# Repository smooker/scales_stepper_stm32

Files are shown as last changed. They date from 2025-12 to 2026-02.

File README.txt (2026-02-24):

Black Pill F4 pinout blackmagic probe
https://github.com/blackmagic-debug/blackmagic/tree/main/src/platforms/common/blackpill-f4

PB8 - SWDCLK - white
PB9 - SWDDIO - gray
GND - purple

Pylnata opitna postanovka - logic analizer + blackmagic probe + stm32f103 blue pill

[Mon Dec  8 10:38:55 2025] usb 3-3: new high-speed USB device number 18 using xhci_hcd
[Mon Dec  8 10:38:56 2025] usb 3-3: New USB device found, idVendor=0403, idProduct=6010, bcdDevice= 7.00
[Mon Dec  8 10:38:56 2025] usb 3-3: New USB device strings: Mfr=1, Product=2, SerialNumber=3
[Mon Dec  8 10:38:56 2025] usb 3-3: Product: USB <-> Serial Converter
[Mon Dec  8 10:38:56 2025] usb 3-3: Manufacturer: FTDI
[Mon Dec  8 10:38:56 2025] usb 3-3: SerialNumber: FT2232HL
[Mon Dec  8 10:38:56 2025] ftdi_sio 3-3:1.0: FTDI USB Serial Device converter detected
[Mon Dec  8 10:38:56 2025] usb 3-3: Detected FT2232H
[Mon Dec  8 10:38:56 2025] usb 3-3: FTDI USB Serial Device converter now attached to ttyUSB0
[Mon Dec  8 10:38:56 2025] ftdi_sio 3-3:1.1: FTDI USB Serial Device converter detected
[Mon Dec  8 10:38:56 2025] usb 3-3: Detected FT2232H
[Mon Dec  8 10:38:56 2025] usb 3-3: FTDI USB Serial Device converter now attached to ttyUSB1
[Mon Dec  8 10:40:39 2025] usb 3-5: new full-speed USB device number 19 using xhci_hcd
[Mon Dec  8 10:40:39 2025] usb 3-5: New USB device found, idVendor=0483, idProduct=5740, bcdDevice= 2.00
[Mon Dec  8 10:40:39 2025] usb 3-5: New USB device strings: Mfr=1, Product=2, SerialNumber=3
[Mon Dec  8 10:40:39 2025] usb 3-5: Product: STM32 Virtual ComPort
[Mon Dec  8 10:40:39 2025] usb 3-5: Manufacturer: STMicroelectronics
[Mon Dec  8 10:40:39 2025] usb 3-5: SerialNumber: 6D8131955348
[Mon Dec  8 10:40:39 2025] cdc_acm 3-5:1.0: ttyACM0: USB ACM device
[Mon Dec  8 10:40:48 2025] usb 3-2: new full-speed USB device number 20 using xhci_hcd
[Mon Dec  8 10:40:48 2025] usb 3-2: New USB device found, idVendor=1d50, idProduct=6018, bcdDevice= 2.00
[Mon Dec  8 10:40:48 2025] usb 3-2: New USB device strings: Mfr=1, Product=2, SerialNumber=3
[Mon Dec  8 10:40:48 2025] usb 3-2: Product: Black Magic Probe (BlackPill-F411CE) v2.0.0-rc1-38-gf4e79b65
[Mon Dec  8 10:40:48 2025] usb 3-2: Manufacturer: Black Magic Debug
[Mon Dec  8 10:40:48 2025] usb 3-2: SerialNumber: 3368334B3134
[Mon Dec  8 10:40:48 2025] cdc_acm 3-2:1.0: ttyACM1: USB ACM device
[Mon Dec  8 10:40:48 2025] cdc_acm 3-2:1.2: ttyACM2: USB ACM device

104849 smooker@sw1 ~/src/stm32/scales_stepper_malinovski $ cat ./USB_DEVICE/App/usbd_desc.c | grep -e USBD_PID -e USBD_VID
#define USBD_VID     1155
#define USBD_PID_FS     22336

104935 smooker@sw1 ~/src/stm32/scales_stepper_malinovski $ hex2dec.pl 1155
HEX:0483
DEC:1155
BIN:     10010000011
104941 smooker@sw1 ~/src/stm32/scales_stepper_malinovski $ hex2dec.pl 22336
HEX:5740
DEC:22336
BIN: 101011101000000
104947 smooker@sw1 ~/src/stm32/scales_stepper_malinovski $

https://github.com/STMicroelectronics/STM32CubeF3/blob/master/Projects/STM32373C_EVAL/Applications/EEPROM/EEPROM_Emulation/Src/eeprom.c

optimize
smooker@sw2 ~/src/stm32/scales_stepper_stm32 $ arm-none-eabi-size ./build/scales_stepper_stm32.elf
   text	   data	    bss	    dec	    hex	filename
  49128	    964	   5568	  55660	   d96c	./build/scales_stepper_stm32.elf

   text	   data	    bss	    dec	    hex	filename
  56336	    964	   5568	  62868	   f594	./build/scales_stepper_stm32.elf

with link.sh
   text	   data	    bss	    dec	    hex	filename
  49128	    964	   5568	  55660	   d96c	./build/scales_stepper_stm32.elf

with newlib 4.6.0
arm-none-eabi-size build/scales_stepper_stm32.elf
   text    data     bss     dec     hex filename
  56312    1196    5568   63076    f664 build/scales_stepper_stm32.elf
arm-none-eabi-objcopy -O ihex build/scales_stepper_stm32.elf build/scales_stepper_stm32.hex

after link.sh
smooker@sw2 ~/src/stm32/scales_stepper_stm32 $ ./link.sh 
   text	   data	    bss	    dec	    hex	filename
  49104	   1196	   5568	  55868	   da3c	./build/scales_stepper_stm32.elf

without enable of printf and scanf
arm-none-eabi-size build/scales_stepper_stm32.elf
   text	   data	    bss	    dec	    hex	filename
  37276	    588	   5560	  43424	   a9a0	build/scales_stepper_stm32.elf
arm-none-eabi-objcopy -O ihex build/scales_stepper_stm32.elf build/scales_stepper_stm32.hex

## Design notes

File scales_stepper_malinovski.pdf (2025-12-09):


21/11/2025

scales_stepper_malinovski Project Configuration Report

## 1. Description

### 1.1. Project

Project Name | scales_stepper_malinovski
Board Name | custom
Generated with: | STM32CubeMX 6.13.0
Date | 11/21/2025

### 1.2. MCU

MCU Series | STM32F1
MCU Line | STM32F103
MCU name | STM32F103C6Tx
MCU Package | LQFP48
MCU Pin number | 48

### 1.3. Core(s) information

Core(s) | Arm Cortex-M3

## 2. Pinout Configuration

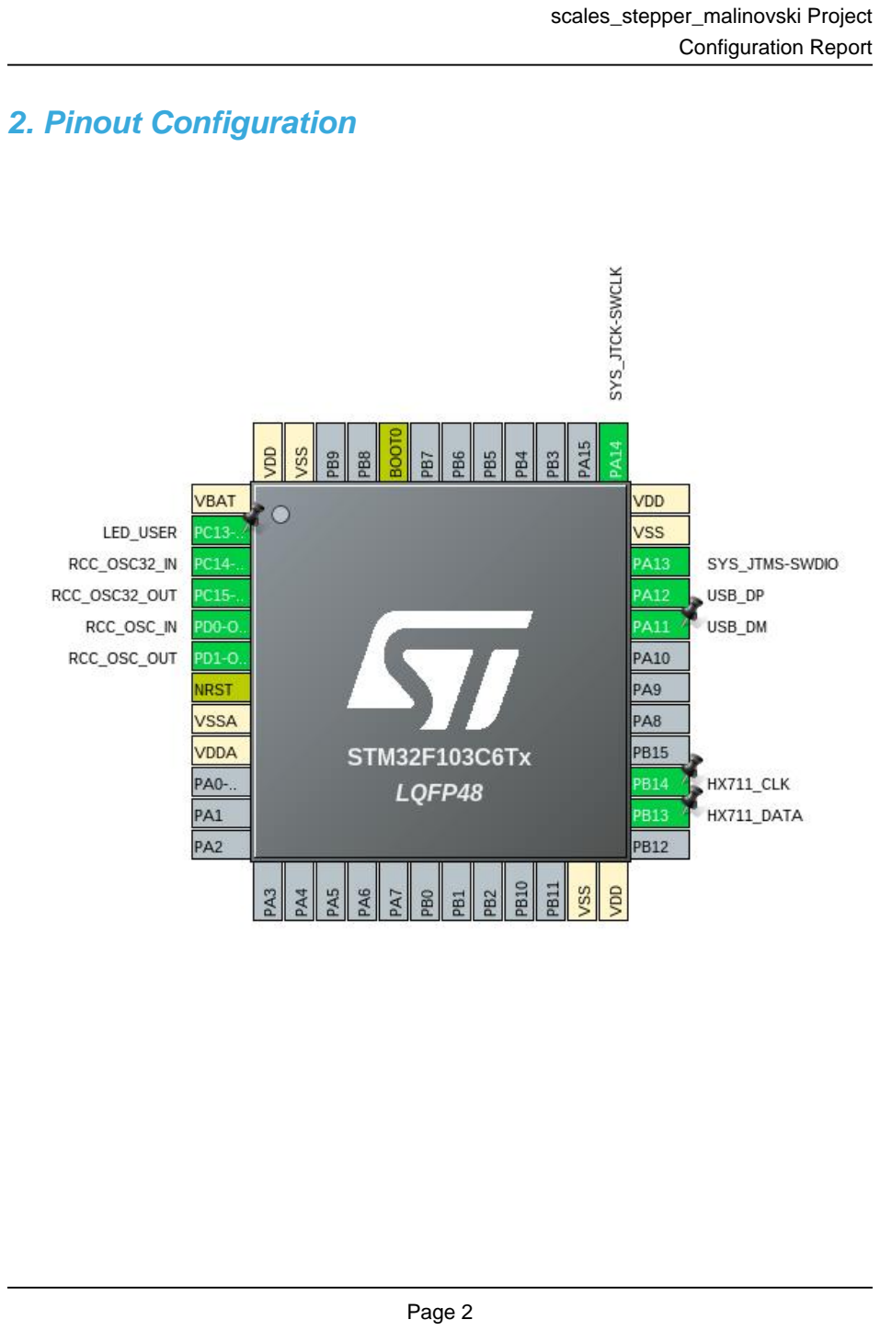
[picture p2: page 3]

## 3. Pins Configuration

Pin Number LQFP48 | Pin Name (function after reset) | Pin Type | Alternate Function(s) | Label
1 | VBAT | Power
2 | PC13-TAMPER-RTC * | I/O | GPIO_Output | LED_USER
3 | PC14-OSC32_IN | I/O | RCC_OSC32_IN
4 | PC15-OSC32_OUT | I/O | RCC_OSC32_OUT
5 | PD0-OSC_IN | I/O | RCC_OSC_IN
6 | PD1-OSC_OUT | I/O | RCC_OSC_OUT
7 | NRST | Reset
8 | VSSA | Power
9 | VDDA | Power
23 | VSS | Power
24 | VDD | Power
26 | PB13 * | I/O | GPIO_Input | HX711_DATA
27 | PB14 * | I/O | GPIO_Output | HX711_CLK
32 | PA11 | I/O | USB_DM
33 | PA12 | I/O | USB_DP
34 | PA13 | I/O | SYS_JTMS-SWDIO
35 | VSS | Power
36 | VDD | Power
37 | PA14 | I/O | SYS_JTCK-SWCLK
44 | BOOT0 | Boot
47 | VSS | Power
48 | VDD | Power

* The pin is affected with an I/O function

## 4. Clock Tree Configuration

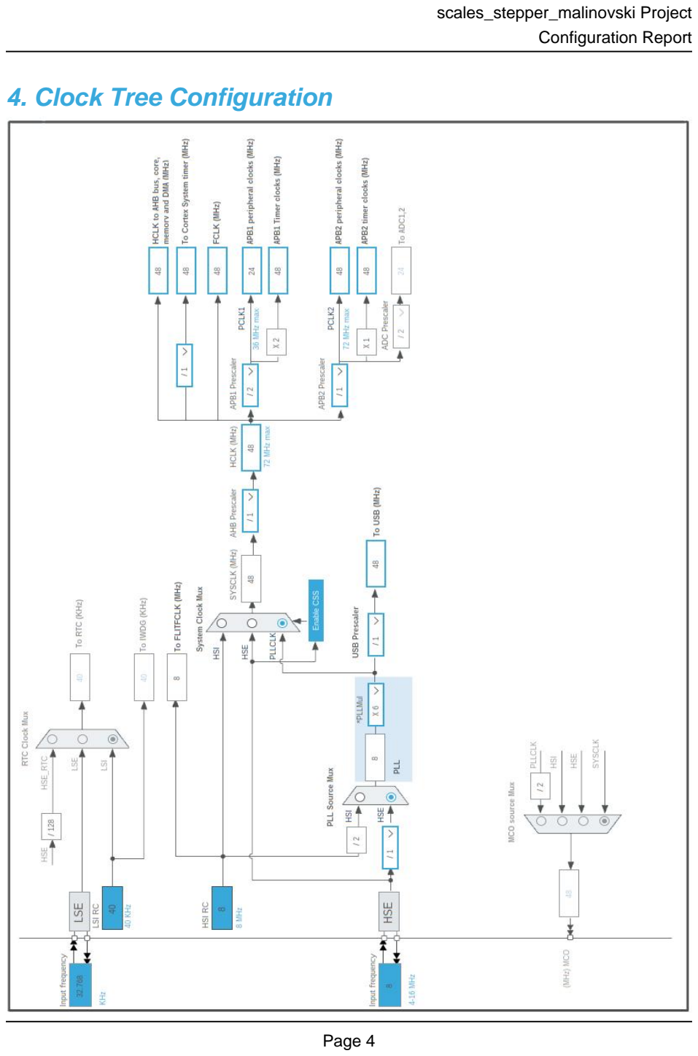
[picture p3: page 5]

## 1. Power Consumption Calculator report

### 1.1. Microcontroller Selection

Series | STM32F1
Line | STM32F103
MCU | STM32F103C6Tx
Datasheet | DS5936_Rev7

### 1.2. Parameter Selection

Temperature | 25
Vdd | 3.3

### 1.3. Battery Selection

Battery | Li-SOCL2(A3400)
Capacity | 3400.0 mAh
Self Discharge | 0.08 %/month
Nominal Voltage | 3.6 V
Max Cont Current | 100.0 mA
Max Pulse Current | 200.0 mA
Cells in series | 1
Cells in parallel | 1

### 1.4. Sequence

Step | Step1 | Step2
Mode | RUN | STOP
Vdd | 3.3 | 3.3
Voltage Source | Battery | Battery
Range | No Scale | No Scale
Fetch Type | FLASH | n/a
CPU Frequency | 72 MHz | 0 Hz
Clock Configuration | HSE PLL | Regulator_LP
Clock Source Frequency | 8 MHz | 0 Hz
Peripherals
Additional Cons. | 0 mA | 0 mA
Average Current | 24.5 mA | 11.7 µA
Duration | 0.1 ms | 0.9 ms
DMIPS | 90.0 | 0.0
Ta Max | 100.55 | 105
Category | In DS Table | In DS Table

### 1.5. Results

Sequence Time | 1 ms | Average Current | 2.46 mA
Battery Life | 1 month, 27 days, 1 hour | Average DMIPS | 61.0 DMIPS

### 1.6. Chart

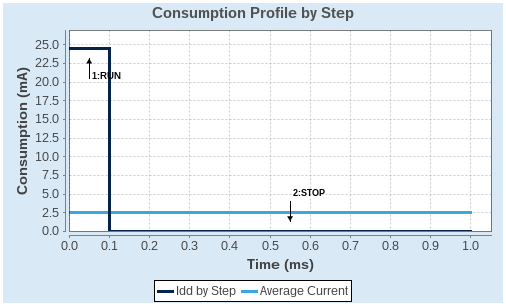
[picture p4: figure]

## 2. Software Project

### 2.1. Project Settings

Name | Value
Project Name | scales_stepper_malinovski
Project Folder | /mnt/hdd/src/stm32/scales_stepper_malinovski
Toolchain / IDE | Makefile
Firmware Package Name and Version | STM32Cube FW_F1 V1.8.6
Application Structure | Advanced
Generate Under Root | No
Do not generate the main() | No
Minimum Heap Size | 0x200
Minimum Stack Size | 0x400

### 2.2. Code Generation Settings

Name | Value
STM32Cube MCU packages and embedded software | Copy all used libraries into the project folder
Generate peripheral initialization as a pair of '.c/.h' files | No
Backup previously generated files when re-generating | No
Keep User Code when re-generating | Yes
Delete previously generated files when not re-generated | Yes
Set all free pins as analog (to optimize the power consumption) | No
Enable Full Assert | No

### 2.3. Advanced Settings - Generated Function Calls

Rank | Function Name | Peripheral Instance Name
1 | SystemClock_Config | RCC
2 | MX_GPIO_Init | GPIO
3 | MX_USB_DEVICE_Init | USB_DEVICE

## 3. Peripherals and Middlewares Configuration

### 3.1. RCC

High Speed Clock (HSE): Crystal/Ceramic Resonator
Low Speed Clock (LSE) : Crystal/Ceramic Resonator
3.1.1. Parameter Settings:

System Parameters:

VDD voltage (V) | 3.3
Prefetch Buffer | Enabled
Flash Latency(WS) | 1 WS (2 CPU cycle)
RCC Parameters:
HSI Calibration Value | 16
HSE Startup Timout Value (ms) | 100
LSE Startup Timout Value (ms) | 5000

### 3.2. SYS

Debug: Serial Wire
Timebase Source: SysTick

### 3.3. USB

mode: Device (FS)
3.3.1. Parameter Settings:

Basic Parameters:

Speed | Full Speed 12MBit/s
Power Parameters:
Low Power | Disabled
Link Power Management | Disabled
Battery Charging | Disabled

### 3.4. USB_DEVICE

Class For FS IP: Communication Device Class (Virtual Port Com)
3.4.1. Parameter Settings:

Basic Parameters:

USBD_MAX_NUM_INTERFACES (Maximum number of supported interfaces) | 1
USBD_MAX_NUM_CONFIGURATION (Maximum number of supported configuration) | 1
USBD_MAX_STR_DESC_SIZ (Maximum size for the string descriptors) | 512
USBD_SELF_POWERED (Enabled self power) | Enabled
USBD_DEBUG_LEVEL (USBD Debug Level) | 0: No debug message
Class Parameters:
USB CDC Rx Buffer Size | 1024
USB CDC Tx Buffer Size | 1024
3.4.2. Device Descriptor:

Device Descriptor:

VID (Vendor IDentifier) | 1155
LANGID_STRING (Language Identifier) | English(United States)
MANUFACTURER_STRING (Manufacturer Identifier) | STMicroelectronics
Device Descriptor FS:
PID (Product IDentifier) | 22336
PRODUCT_STRING (Product Identifier) | STM32 Virtual ComPort
CONFIGURATION_STRING (Configuration Identifier) | CDC Config
INTERFACE_STRING (Interface Identifier) | CDC Interface

* User modified value

## 4. System Configuration

### 4.1. GPIO configuration

IP | Pin | Signal | GPIO mode | GPIO pull/up pull down | Max Speed | User Label
RCC | PC14-OSC32_IN | RCC_OSC32_IN | n/a | n/a | n/a
| PC15-OSC32_OU T | RCC_OSC32_O UT | n/a | n/a | n/a
| PD0-OSC_IN | RCC_OSC_IN | n/a | n/a | n/a
| PD1-OSC_OUT | RCC_OSC_OUT | n/a | n/a | n/a
SYS | PA13 | SYS_JTMS-SWDIO | n/a | n/a | n/a
| PA14 | SYS_JTCK-SWCLK | n/a | n/a | n/a
USB | PA11 | USB_DM | n/a | n/a | n/a
| PA12 | USB_DP | n/a | n/a | n/a
GPIO | PC13-TAMPER-RTC | GPIO_Output | Output Push Pull | No pull-up and no pull-down | Low | LED_USER
| PB13 | GPIO_Input | Input mode | No pull-up and no pull-down | n/a | HX711_DATA
| PB14 | GPIO_Output | Output Push Pull | No pull-up and no pull-down | Low | HX711_CLK

### 4.2. DMA configuration

nothing configured in DMA service

### 4.3. NVIC configuration

4.3.1. NVIC
Interrupt Table | Enable | Preenmption Priority | SubPriority
Non maskable interrupt | true | 0 | 0
Hard fault interrupt | true | 0 | 0
Memory management fault | true | 0 | 0
Prefetch fault, memory access fault | true | 0 | 0
Undefined instruction or illegal state | true | 0 | 0
System service call via SWI instruction | true | 0 | 0
Debug monitor | true | 0 | 0
Pendable request for system service | true | 0 | 0
System tick timer | true | 15 | 0
USB low priority or CAN RX0 interrupts | true | 0 | 0
PVD interrupt through EXTI line 16 | unused
Flash global interrupt | unused
RCC global interrupt | unused
USB high priority or CAN TX interrupts | unused
4.3.2. NVIC Code generation
Enabled interrupt Table | Select for init sequence ordering | Generate IRQ handler | Call HAL handler
Non maskable interrupt | false | true | false
Hard fault interrupt | false | true | false
Memory management fault | false | true | false
Prefetch fault, memory access fault | false | true | false
Undefined instruction or illegal state | false | true | false
System service call via SWI instruction | false | true | false
Debug monitor | false | true | false
Pendable request for system service | false | true | false
System tick timer | false | true | true
USB low priority or CAN RX0 interrupts | false | true | true

* User modified value

## 5. System Views

5.1. Category view
5.1.1. Current

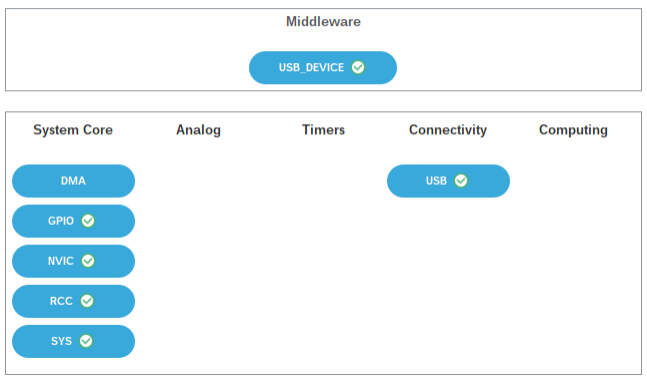
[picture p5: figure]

## 6. Docs & Resources

Type | Link
BSDL files | https://www.st.com/resource/en/bsdl_model/stm32f1_bsdl.zip
IBIS models | https://www.st.com/resource/en/ibis_model/stm32f1-ibis.zip
System View Description | https://www.st.com/resource/en/svd/stm32f1_svd.zip
Presentations | https://www.st.com/resource/en/product_presentation/stm32-stm8_embedded_software_solutions.pdf
Presentations | https://www.st.com/resource/en/product_presentation/stm32_eval-tools_portfolio.pdf
Presentations | https://www.st.com/resource/en/product_presentation/stm32_stm8_functi onal-safety-packages.pdf
Presentations | https://www.st.com/resource/en/product_presentation/stm32-stm8_software_development_tools.pdf
Presentations | https://www.st.com/resource/en/product_presentation/microcontrollers-stm32-family-overview.pdf
Brochures | https://www.st.com/resource/en/brochure/products-and-solutions-for-plcs-and-smart-i-os.pdf
Brochures | https://www.st.com/resource/en/brochure/expansion-boards-for-intelligent-power-switches.pdf
Flyers | https://www.st.com/resource/en/flyer/flstm32nucleo.pdf
Flyers | https://www.st.com/resource/en/flyer/fldpstpfc11120.pdf
Product Certifications | https://www.st.com/resource/en/certification_document/1239988349.pdf
Product Certifications | https://www.st.com/resource/en/certification_document/stm32_authentication_can.pdf
Security Bulletin | https://www.st.com/resource/en/technical_note/tn1489-security-bulletin-tn1489stpsirt-physical-attacks-on-stm32-and-stm32cube-firmware-stmicroelectronics.pdf
Application Notes | https://www.st.com/resource/en/application_note/an1709-emc-design-guide-for-stm8-stm32-and-legacy-mcus-stmicroelectronics.pdf

Application Notes | https://www.st.com/resource/en/application_note/an2586-getting-started-with-stm32f10xxx-hardware-development-stmicroelectronics.pdf
Application Notes | https://www.st.com/resource/en/application_note/an2604-stm32f101xx-and-stm32f103xx-rtc-calibration-stmicroelectronics.pdf
Application Notes | https://www.st.com/resource/en/application_note/an2945-stm8s-and-stm32-mcus-a-consistent-832bit-product-line-for-painless-migration-stmicroelectronics.pdf
Application Notes | https://www.st.com/resource/en/application_note/an3070-managing-the-driver-enable-signal-for-rs485-and-iolink-communications-with-the-stm32s-usart-stmicroelectronics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
Application Notes | https://www.st.com/resource/en/application_note/an3095-stevalisv002v1-stevalisv002v2-3-kw-gridconnected-pv-system-based-on-the-stm32f103xx-stmicroelectronics.pdf
Application Notes | https://www.st.com/resource/en/application_note/an3108-stlm75-firmware-library-for-the-stm32f10x-stmicroelectronics.pdf
Application Notes | https://www.st.com/resource/en/application_note/an3126-audio-and-waveform-generation-using-the-dac-in-stm32-products-stmicroelectronics.pdf
Application Notes | https://www.st.com/resource/en/application_note/an3128-stm32-embedded-graphic-objectstouchscreen-library-stmicroelectronics.pdf
Application Notes | https://www.st.com/resource/en/application_note/an3155-usart-protocol-used-in-the-stm32-bootloader-stmicroelectronics.pdf
Application Notes | https://www.st.com/resource/en/application_note/an3156-usb-dfu-protocol-used-in-the-stm32-bootloader-stmicroelectronics.pdf
Application Notes | https://www.st.com/resource/en/application_note/an3364-migration-and-compatibility-guidelines-for-stm32-microcontroller-applications-stmicroelectronics.pdf
Application Notes | https://www.st.com/resource/en/application_note/an3422-migration-of-microcontroller-applications-from-stm32f1-to-stm32l1-series-stmicroelectronics.pdf
Application Notes | https://www.st.com/resource/en/application_note/an3427-migrating-a-microcontroller-application-from-stm32f1-to-stm32f2-series-stmicroelectronics.pdf

Application Notes | https://www.st.com/resource/en/application_note/an3429-stm32-proprietary-code-protection-overview-stmicroelectronics.pdf
Application Notes | https://www.st.com/resource/en/application_note/an4070-250-w-grid-connected-microinverter-stmicroelectronics.pdf
Application Notes | https://www.st.com/resource/en/application_note/an4076-two-or-three-shunt-resistor-based-current-sensing-circuit-design-in-3phase-inverters-stmicroelectronics.pdf
Application Notes | https://www.st.com/resource/en/application_note/an4088-migrating-between-stm32f1-and-stm32f0-series-microcontrollers-stmicroelectronics.pdf
Application Notes | https://www.st.com/resource/en/application_note/an4228-migrating-from-stm32f1-series-to-stm32f3-series-microcontrollers-stmicroelectronics.pdf
Application Notes | https://www.st.com/resource/en/application_note/an4649-migrating-from-stm32f1-series-to-stm32l4-series--stm32l4-series-microntrollers-stmicroelectronics.pdf
Application Notes | https://www.st.com/resource/en/application_note/an4655-virtually-increasing-the-number-of-serial-communication-peripherals-in-stm32-applications-stmicroelectronics.p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
Application Notes | https://www.st.com/resource/en/application_note/an4724-stm32cube-firmware-examples-for-stm32f1-series-stmicroelectronics.pdf
Application Notes | https://www.st.com/resource/en/application_note/an4750-handling-of-soft-errors-in-stm32-applications-stmicroelectronics.pdf
Application Notes | https://www.st.com/resource/en/application_note/an4776-generalpurpose-timer-cookbook-for-stm32-microcontrollers-stmicroelectronics.pdf
Application Notes | https://www.st.com/resource/en/application_note/an4803-highspeed-si-simulations-using-ibis-and-boardlevel-simulations-using-hyperlynx-si-on-stm32-mcus-and-mpus-stmic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
Application Notes | https://www.st.com/resource/en/application_note/an4904-migration-of-microcontroller-applications-from-stm32f1-series-to-stm32f4-access-lines-stmicroelectronics.pdf
Application Notes | https://www.st.com/resource/en/application_note/an4989-stm32-microcontroller-debug-toolbox-stmicroelectronics.pdf
Application Notes | https://www.st.com/resource/en/application_note/an5027-interfacing-pdm-

| digital-microphones-using-stm32-mcus-and-mpus-stmicroelectronics.pdf
Application Notes | https://www.st.com/resource/en/application_note/an4899-stm32-microcontroller-gpio-hardware-settings-and-lowpower-consumption-stmicroelectronics.pdf
Application Notes | https://www.st.com/resource/en/application_note/an5612-esd-protection-of-stm32-mcus-and-mpus-stmicroelectronics.pdf
Application Notes | https://www.st.com/resource/en/application_note/an4838-introduction-to-memory-protection-unit-management-on-stm32-mcus-stmicroelectronics.pdf
Application Notes | https://www.st.com/resource/en/application_note/an4879-introduction-to-usb-hardware-and-pcb-guidelines-using-stm32-mcus-stmicroelectronics.pdf
Application Notes | https://www.st.com/resource/en/application_note/an5225-introduction-to-usb-typec-power-delivery-for-stm32-mcus-and-mpus-stmicroelectronics.pdf
Application Notes | https://www.st.com/resource/en/application_note/an5537-how-to-use-adc-oversampling-techniques-to-improve-signaltonoise-ratio-on-stm32-mcus-stmicroelectronics.pdf
Application Notes | https://www.st.com/resource/en/application_note/an5036-guidelines-for-thermal-management-on-stm32-applications-stmicroelectronics.pdf
Application Notes | https://www.st.com/resource/en/application_note/an2548-introduction-to-dma-controller-for-stm32-mcus-stmicroelectronics.pdf
Application Notes | https://www.st.com/resource/en/application_note/an4013-introduction-to-timers-for-stm32-mcus-stmicroelectronics.pdf
Application Notes | https://www.st.com/resource/en/application_note/an4277-how-to-use-pwm-shutdown-for-motor-control-and-digital-power-conversion-on-stm32-mcus-stmicroelectronics.pdf
Application Notes | https://www.st.com/resource/en/application_note/an4908-getting-started-with-usart-automatic-baud-rater-detection-for-stm32-mcus-stmicroelectronics.pdf
Application Notes | https://www.st.com/resource/en/application_note/an5156-introduction-to-security-for-stm32-mcus-stmicroelectronics.pdf
Application Notes | https://www.st.com/resource/en/application_note/an5543-guidelines-for-

| enhanced-spi-communication-on-stm32-mcus-and-mpus-stmicroelectronics.pdf
Application Notes | https://www.st.com/resource/en/application_note/cd00211314-how-to-optimize-the-adc-accuracy-in-the-stm32-mcus-stmicroelectronics.pdf
Application Notes | https://www.st.com/resource/en/application_note/an2639-soldering-recommendations-and-package-information-for-leadfree-ecopack2-mcus-and-mpus-stmicroelectronics.pdf
Application Notes | https://www.st.com/resource/en/application_note/an3154-how-to-use-can-protocol-in-bootloader-on-stm32-mcus-stmicroelectronics.pdf
Application Notes | https://www.st.com/resource/en/application_note/an4566-how-to-extend-the-dac-performance-on-stm32-mcus-stmicroelectronics.pdf
Application Notes | https://www.st.com/resource/en/application_note/an5647-the-goertzel-algorithm-to-compute-individual-terms-of-the-discrete-fourier-transform-dft-in-stm32-products-stm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
Application Notes | https://www.st.com/resource/en/application_note/an2606-introduction-to-system-memory-boot-mode-on-stm32-mcus-stmicroelectronics.pdf
Application Notes for related Tools & Software | https://www.st.com/resource/en/application_note/an2557-stm32f10x-inapplication-programming-using-the-usart-stmicroelectronics.pdf
Application Notes for related Tools & Software | https://www.st.com/resource/en/application_note/an2592-achieving-32bit-timer-resolution-with-software-expansion-for-stm32cube-and-standard-peripheral-library-stmicro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
Application Notes for related Tools & Software | https://www.st.com/resource/en/application_note/an2594-eeprom-emulation-in-stm32f10x-microcontrollers-stmicroelectronics.pdf
Application Notes for related Tools & Software | https://www.st.com/resource/en/application_note/an2598-smartcard-interface-with-stm32f10x-and-stm32l1xx-microcontrollers-stmicroelectronics.pdf
Application Notes for related Tools & Software | https://www.st.com/resource/en/application_note/an2629-stm32f101xx-stm32f102xx-and-stm32f103xx-lowpower-modes-stmicroelectronics.pdf
Application Notes for related Tools & Software | https://www.st.com/resource/en/application_note/an2656-stm32f10xxx-lcd-glass-driver-firmware-stmicroelectronics.pdf

Application Notes for related Tools & Software | https://www.st.com/resource/en/application_note/an2668-improving-stm32f1-series-stm32f3-series-and-stm32lx-series-adc-resolution-by-oversampling-stmicroelectronics.p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
Application Notes for related Tools & Software | https://www.st.com/resource/en/application_note/an2739-how-to-use-the-highdensity-stm32f103xx-microcontroller-to-play-audio-files-with-an-external-is-audio-codec-stm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
Application Notes for related Tools & Software | https://www.st.com/resource/en/application_note/an2790-tft-lcd-interfacing-with-the-highdensity-stm32f10xxx-fsmc-stmicroelectronics.pdf
Application Notes for related Tools & Software | https://www.st.com/resource/en/application_note/an2820-driving-bipolar-stepper-motors-using-a-mediumdensity-stm32f103xx-microcontroller-stmicroelectronics.pdf
Application Notes for related Tools & Software | https://www.st.com/resource/en/application_note/an2821-clockcalendar-implementation-on-the-stm32f10xxx-microcontroller-rtc-stmicroelectronics.pdf
Application Notes for related Tools & Software | https://www.st.com/resource/en/application_note/an2824-stm32f10xxx-ic-optimized-examples-stmicroelectronics.pdf
Application Notes for related Tools & Software | https://www.st.com/resource/en/application_note/an2841-led-dimming-implemented-on-stm32-microcontroller-stmicroelectronics.pdf
Application Notes for related Tools & Software | https://www.st.com/resource/en/application_note/an2868-stm32f10xxx-internal-rc-oscillator-hsi-calibration-stmicroelectronics.pdf
Application Notes for related Tools & Software | https://www.st.com/resource/en/application_note/an2931-implementing-the-adpcm-algorithm-in-highdensity-stm32f103xx-microcontrollers-stmicroelectronics.pdf
Application Notes for related Tools & Software | https://www.st.com/resource/en/application_note/an2953-how-to-migrate-from-the-stm32f10xxx-firmware-library-v203-to-the-stm32f10xxx-standard-peripheral-library-v300-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
Application Notes for related Tools & Software | https://www.st.com/resource/en/application_note/an3012-getting-started-with-uclinux-for-stm32f10x-highdensity-devices-stmicroelectronics.pdf
Application Notes | https://www.st.com/resource/en/application_note/an3078-stm32-

for related Tools & Software | inapplication-programming-over-the-ic-bus-stmicroelectronics.pdf
Application Notes for related Tools & Software | https://www.st.com/resource/en/application_note/an3109-communication-peripheral-fifo-emulation-with-dma-and-dma-timeout-in-stm32f10x-microcontrollers-stmicroelectron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
Application Notes for related Tools & Software | https://www.st.com/resource/en/application_note/an3116-stm32s-adc-modes-and-their-applications-stmicroelectronics.pdf
Application Notes for related Tools & Software | https://www.st.com/resource/en/application_note/an3174-implementing-receivers-for-infrared-remote-control-protocols-using-stm32f10xxx-microcontrollers-stmicroelectro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
Application Notes for related Tools & Software | https://www.st.com/resource/en/application_note/an3241-qvga-tftlcd-direct-drive-using-the-stm32f10xx-fsmc-peripheral-stmicroelectronics.pdf
Application Notes for related Tools & Software | https://www.st.com/resource/en/application_note/an3307-guidelines-for-obtaining-iec-60335-class-b-certification-for-any-stm32-application-stmicroelectronics.pdf
Application Notes for related Tools & Software | https://www.st.com/resource/en/application_note/an3970-plm-smartplug-v2-getting-started-stmicroelectronics.pdf
Application Notes for related Tools & Software | https://www.st.com/resource/en/application_note/an3991-how-to-drive-multiple-stepper-motors-with-the-l6470-motor-driver-stmicroelectronics.pdf
Application Notes for related Tools & Software | https://www.st.com/resource/en/application_note/an4075-stevalifp016v2-iolink-communication-master-transceiver-demonstration-board-stmicroelectronics.pdf
Application Notes for related Tools & Software | https://www.st.com/resource/en/application_note/an4323-getting-started-with-stemwin-library-stmicroelectronics.pdf
Application Notes for related Tools & Software | https://www.st.com/resource/en/application_note/an4435-guidelines-for-obtaining-ulcsaiec-607301603351-class-b-certification-in-any-stm32-application-stmicroelectroni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

Application Notes
for related Tools

https://www.st.com/resource/en/application_note/an4453-implementingthe-adpcm-algorithm-in-stm32l1xx-microcontrollers-stmicroelectronics.pdf

& Software
Application Notes for related Tools & Software | https://www.st.com/resource/en/application_note/an4499-stm32--nrf51822-bluetooth-low-energy-system-solution-stmicroelectronics.pdf
Application Notes for related Tools & Software | https://www.st.com/resource/en/application_note/an4578-16channels-led-driver-with-independent-pwm-dimming-control-based-on-led7708-stmicroelectronics.pdf
Application Notes for related Tools & Software | https://www.st.com/resource/en/application_note/an4657-stm32-inapplication-programming-iap-using-the-usart-stmicroelectronics.pdf
Application Notes for related Tools & Software | https://www.st.com/resource/en/application_note/an4724-stm32cube-firmware-examples-for-stm32f1-series-stmicroelectronics.pdf
Application Notes for related Tools & Software | https://www.st.com/resource/en/application_note/an4841-digital-signal-processing-for-stm32-microcontrollers-using-cmsis-stmicroelectronics.pdf
Application Notes for related Tools & Software | https://www.st.com/resource/en/application_note/an5360-getting-started-with-projects-based-on-the-stm32mp1-series-in-stm32cubeide-stmicroelectronics.pdf
Application Notes for related Tools & Software | https://www.st.com/resource/en/application_note/an5361-getting-started-with-projects-based-on-dualcore-stm32h7-microcontrollers-in-stm32cubeide-stmicroelectronics.pd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
Application Notes for related Tools & Software | https://www.st.com/resource/en/application_note/an5394-getting-started-with-projects-based-on-the-stm32l5-series-in-stm32cubeide-stmicroelectronics.pdf
Application Notes for related Tools & Software | https://www.st.com/resource/en/application_note/an5418-how-to-build-a-simple-usbpd-sink-application-with-stm32cubemx-stmicroelectronics.pdf
Application Notes for related Tools & Software | https://www.st.com/resource/en/application_note/an5426-migrating-graphics-middleware-projects-from-stm32cubemx-540-to-stm32cubemx-550-stmicroelectronics.pdf
Application Notes for related Tools & Software | https://www.st.com/resource/en/application_note/an5564-getting-started-with-projects-based-on-dualcore-stm32wl-microcontrollers-in-stm32cubeide-stmicroelectronics.pd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

Application Notes for related Tools & Software | https://www.st.com/resource/en/application_note/an5698-adapting-the-xcubestl-functional-safety-package-for-stm32-iec-61508-compliant-to-other-safety-standards-stmicr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
Application Notes for related Tools & Software | https://www.st.com/resource/en/application_note/an5731-stm32cubemx-and-stm32cubeide-threadsafe-solution-stmicroelectronics.pdf
Application Notes for related Tools & Software | https://www.st.com/resource/en/application_note/an4502-stm32-smbuspmbus-expansion-package-for-stm32cube-stmicroelectronics.pdf
Application Notes for related Tools & Software | https://www.st.com/resource/en/application_note/an5952-how-to-use-cmake-in-stm32cubeide-stmicroelectronics.pdf
Application Notes for related Tools & Software | https://www.st.com/resource/en/application_note/an5054-how-to-perform-secure-programming-using-stm32cubeprogrammer-stmicroelectronics.pdf
Application Notes for related Tools & Software | https://www.st.com/resource/en/application_note/an6179-how-to-integrate-the-stl-firmware-into-a-time-critical-user-application-stmicroelectronics.pdf
Application Notes for related Tools & Software | https://www.st.com/resource/en/application_note/an6127-getting-started-with-stm32h7rx7sx-mcus-in-stm32cubeide-stmicroelectronics.pdf
Application Notes for related Tools & Software | https://www.st.com/resource/en/application_note/an6265-getting-started-with-stm32n6-mcus-in-stm32cubeide-stmicroelectronics.pdf
Device Option Lists | https://www.st.com/resource/en/device_option_list/opl_stm32f103_32k.zip
Errata Sheets | https://www.st.com/resource/en/errata_sheet/es0348-stm32f101x46-stm32f102x46-stm32f103x46-device-errata-stmicroelectronics.pdf
Datasheet | https://www.st.com/resource/en/datasheet/cd00210843.pdf
Programming Manuals | https://www.st.com/resource/en/programming_manual/pm0056-stm32f10xxx20xxx21xxxl1xxxx-cortexm3-programming-manual-stmicroelectronics.pdf
Programming Manuals | https://www.st.com/resource/en/programming_manual/pm0075-stm32f10xxx-flash-memory-microcontrollers-stmicroelectronics.pdf

Reference Manuals | https://www.st.com/resource/en/reference_manual/rm0008-stm32f101xx-stm32f102xx-stm32f103xx-stm32f105xx-and-stm32f107xx-advanced-armbased-32bit-mcus-stmicroelectronic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
Technical Notes & Articles | https://www.st.com/resource/en/technical_note/tn0516-overview-of-the-stm32f0xf100xxf103xx-and-stm32f2xxf30xf4xx-mcus-pmsm-singledual-foc-sdk-v40-stmicroelectronics.p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
Technical Notes & Articles | https://www.st.com/resource/en/technical_note/tn1163-description-of-wlcsp-for-microcontrollers-and-recommendations-for-its-use-stmicroelectronics.pdf
Technical Notes & Articles | https://www.st.com/resource/en/technical_note/tn1204-tape-and-reel-shipping-media-for-stm32-microcontrollers-in-bga-packages-stmicroelectronics.pdf
Technical Notes & Articles | https://www.st.com/resource/en/technical_note/tn1205-tape-and-reel-shipping-media-for-stm8-and-stm32-microcontrollers-in-fpn-packages-stmicroelectronics.pdf
Technical Notes & Articles | https://www.st.com/resource/en/technical_note/tn1206-tape-and-reel-shipping-media-for-stm8-and-stm32-microcontrollers-in-qfp-packages-stmicroelectronics.pdf
Technical Notes & Articles | https://www.st.com/resource/en/technical_note/tn1207-tape-and-reel-shipping-media-for-stm8-and-stm32-microcontrollers-in-so-packages-stmicroelectronics.pdf
Technical Notes & Articles | https://www.st.com/resource/en/technical_note/tn1208-tape-and-reel-shipping-media-for-stm8-and-stm32-microcontrollers-in-tssop-and-ssop-packages-stmicroelectronics.p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
Technical Notes & Articles | https://www.st.com/resource/en/technical_note/tn1433-reference-device-marking-schematics-for-stm32-microcontrollers-and-microprocessors-stmicroelectronics.pdf
User Manuals | https://www.st.com/resource/en/user_manual/um1561-stevalisv003v1-firmware-user-manual-stmicroelectronics.pdf
User Manuals | https://www.st.com/resource/en/user_manual/um1573-st7540-power-line-modem-firmware-stack-stmicroelectronics.pdf

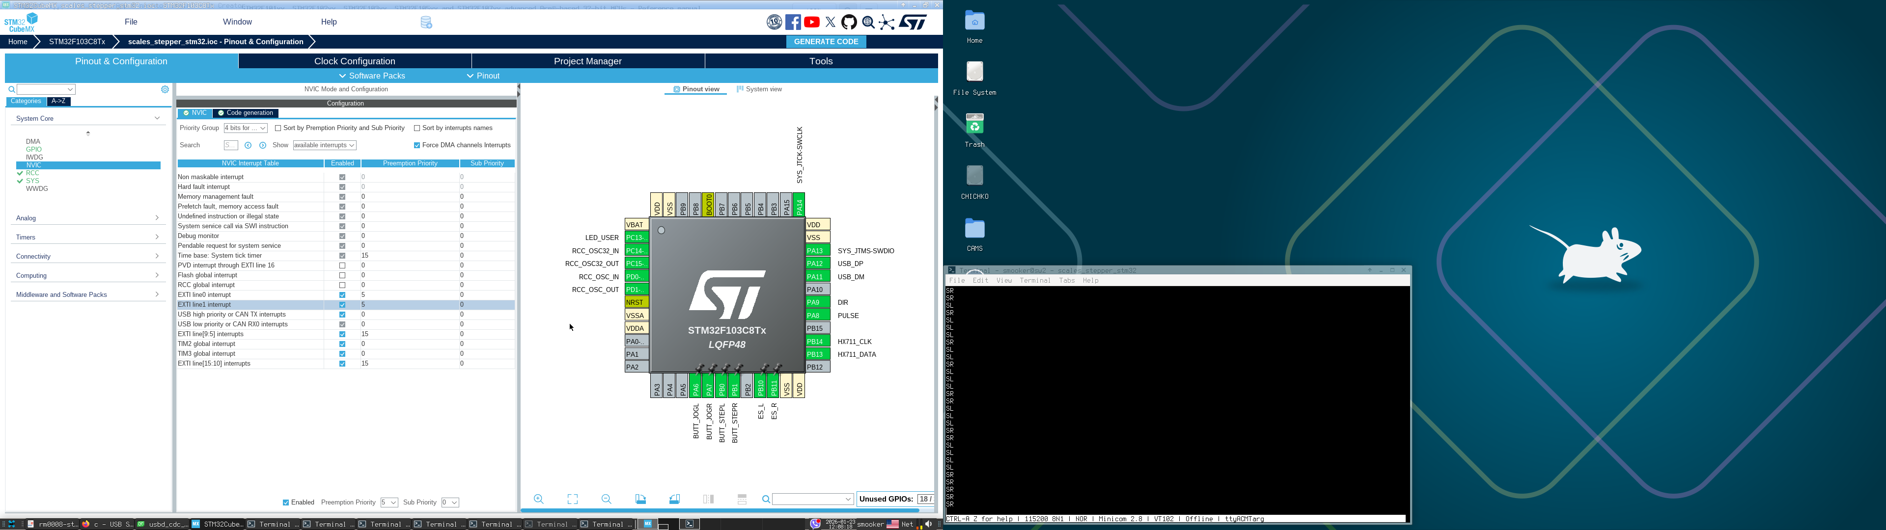
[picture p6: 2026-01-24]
docs/nvic_prios_Screenshot_2026-01-23_12-08-20.png

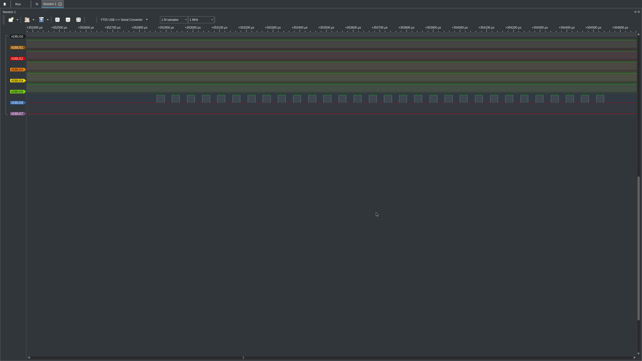
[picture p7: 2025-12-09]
docs/Screenshot_2025-12-01_11-15-23.png

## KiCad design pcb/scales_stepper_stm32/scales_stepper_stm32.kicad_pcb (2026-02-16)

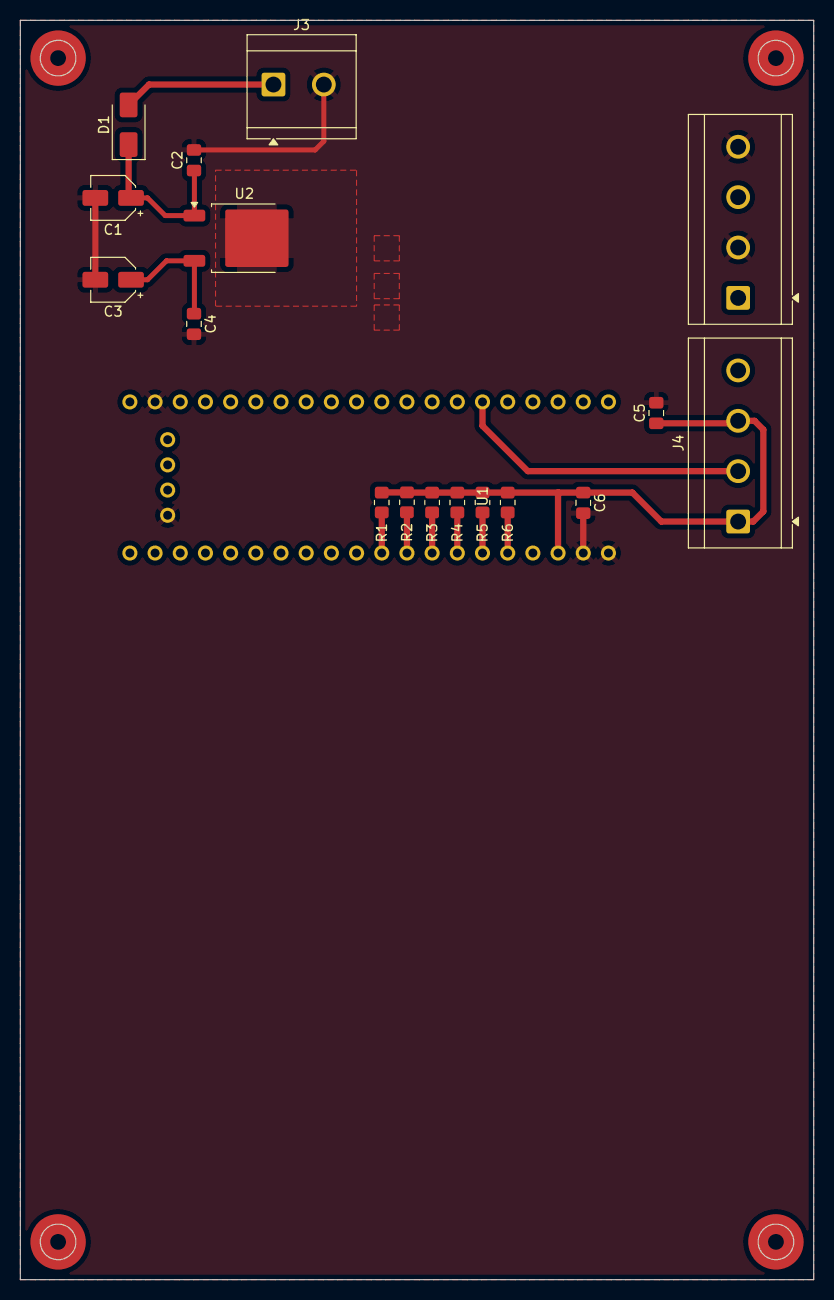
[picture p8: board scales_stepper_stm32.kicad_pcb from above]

Board: 2 copper layers, 80.0 x 127.0 mm, 18 parts (0 on the bottom side), 13 nets.

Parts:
C1, C3: 47u; CP_Elec_4x4.5
C2, C4, C5, C6: 100n; C_0805_2012Metric_Pad1.18x1.45mm_HandSolder
D1: SS3200; D_SMA
J3: Screw_Terminal_01x02; TerminalBlock_CUI_TB007-508-02_1x02_P5.08mm_Horizontal
J4, J5: Screw_Terminal_01x04; TerminalBlock_CUI_TB007-508-04_1x04_P5.08mm_Horizontal
R1, R2, R3, R4, R5, R6: 1k; R_0805_2012Metric_Pad1.20x1.40mm_HandSolder
U1: BP; blue_pill
U2: LM78M05_TO252; TO-252-2

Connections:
+3V3: C5.1, C6.1, J4.1, J4.3, R1.1, R2.1, R3.1, R4.1, R5.1, R6.1, U1.3V3 (3.3V)
+5V: C3.1, C4.1, U2.3 (VO)
+24V: D1.2 (A), J3.1
BUTT_JOGL: R1.2, U1.PA6
BUTT_JOGR: R2.2, U1.PA7
BUTT_STEPL: R3.2, U1.PB0
BUTT_STEPR: R4.2, U1.PB1
DIR: J4.2, U1.PA9
ES_L: J5.1, R5.2, U1.PB10
ES_R: J5.3, R6.2, U1.PB11
GND: C1.2, C2.2, C3.2, C4.2, C5.2, C6.2, J3.2, J5.2, J5.4, U1.G (GND), U2.2 (GND)
unnamed: C1.1, C2.1, D1.1 (K), U2.1 (VI)
PULSE: J4.4, U1.PA8

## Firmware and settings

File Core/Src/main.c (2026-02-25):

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
/* Includes ------------------------------------------------------------------*/
#include "main.h"
#include "usb_device.h"

/* USER CODE BEGIN Includes */
#include "usb_device.h"
#include "usbd_cdc_if.h"
#include "stdarg.h"
#include "stdio.h"
#include <inttypes.h>
#include "eeprom.h"

/* USER CODE END Includes */

TIM_HandleTypeDef htim1;
TIM_HandleTypeDef htim2;
TIM_HandleTypeDef htim3;

/* USER CODE BEGIN PV */

//
typedef struct
{
  uint32_t spsmax;          //steps per seconds maximum
  uint32_t spsmin;          //steps per seconds minimum
  uint32_t spsps;           //steps per second per second
  uint32_t jogsteps;        //jog steps
  uint32_t ssteps;          //steps steps
  uint32_t spmm;            //steps per mm
  float spsmax2;            //
  float spsmin2;
  float spsps2;
  float jogsteps2;
  float ssteps2;
} storage_t;

//
typedef struct
{
 uint16_t lsb;
 uint16_t msb;
} addr32_t;

typedef struct
{
 int32_t big;
 uint32_t lit;
} tuple64;

volatile storage_t ee_data;

// define bitwises for semaphore
#define JOGL        0
#define JOGR        1
#define JOGSTEPL    2
#define JOGSTEPR    3
#define STEPL       4
#define STEPR       5
#define EL          6
#define ER          7
#define EE          8
#define JOGL_DB     9
#define JOGR_DB     10
#define JOGSTEPL_DB 11
#define JOGSTEPR_DB 12
#define STEPL_DB    13
#define STEPR_DB    14
#define EL_DB       15
#define ER_DB       16
#define EE_DB       17
#define IN_HOMING   18

//PIN JOGS
#define PIN_JOGL_RESET  (HAL_GPIO_ReadPin(BUTT_JOGL_GPIO_Port, BUTT_JOGL_Pin) == GPIO_PIN_RESET)
#define PIN_JOGL_SET    (HAL_GPIO_ReadPin(BUTT_JOGL_GPIO_Port, BUTT_JOGL_Pin) == GPIO_PIN_SET)
#define PIN_JOGR_RESET  (HAL_GPIO_ReadPin(BUTT_JOGR_GPIO_Port, BUTT_JOGR_Pin) == GPIO_PIN_RESET)
#define PIN_JOGR_SET    (HAL_GPIO_ReadPin(BUTT_JOGR_GPIO_Port, BUTT_JOGR_Pin) == GPIO_PIN_SET)

//PIN STEPS
#define PIN_STEPL_RESET (HAL_GPIO_ReadPin(BUTT_STEPL_GPIO_Port, BUTT_STEPL_Pin) == GPIO_PIN_RESET)
#define PIN_STEPL_SET   (HAL_GPIO_ReadPin(BUTT_STEPL_GPIO_Port, BUTT_STEPL_Pin) == GPIO_PIN_SET)
#define PIN_STEPR_RESET (HAL_GPIO_ReadPin(BUTT_STEPR_GPIO_Port, BUTT_STEPR_Pin) == GPIO_PIN_RESET)
#define PIN_STEPR_SET   (HAL_GPIO_ReadPin(BUTT_STEPR_GPIO_Port, BUTT_STEPR_Pin) == GPIO_PIN_SET)

//PIN E
#define PIN_EL_RESET    (HAL_GPIO_ReadPin(ES_L_GPIO_Port, ES_L_Pin) == GPIO_PIN_RESET)
#define PIN_EL_SET      (HAL_GPIO_ReadPin(ES_L_GPIO_Port, ES_L_Pin) == GPIO_PIN_SET)
#define PIN_ER_RESET    (HAL_GPIO_ReadPin(ES_R_GPIO_Port, ES_R_Pin) == GPIO_PIN_RESET)
#define PIN_ER_SET      (HAL_GPIO_ReadPin(ES_R_GPIO_Port, ES_R_Pin) == GPIO_PIN_SET)

//SEMAPHORES
#define SEM_EL          ((semaphore & (1 << EL)) > 0)
#define SEM_ER          ((semaphore & (1 << ER)) > 0)
#define SEM_JOGL        ((semaphore & (1 << JOGL)) > 0)
#define SEM_JOGR        ((semaphore & (1 << JOGR)) > 0)
#define SEM_JOGSTEPL    ((semaphore & (1 << JOGSTEPL)) > 0)
#define SEM_JOGSTEPR    ((semaphore & (1 << JOGSTEPR)) > 0)
#define SEM_STEPL       ((semaphore & (1 << STEPL)) > 0)
#define SEM_STEPR       ((semaphore & (1 << STEPR)) > 0)
#define SEM_IN_HOMING   ((semaphore & (1 << IN_HOMING)) > 0)

//DEBOUNCES
#define DB_JOGL         ((semaphore & (1 << JOGL_DB)) > 0)
#define DB_JOGR         ((semaphore & (1 << JOGR_DB)) > 0)
#define DB_STEPL        ((semaphore & (1 << STEPL_DB)) > 0)
#define DB_STEPR        ((semaphore & (1 << STEPR_DB)) > 0)
#define DB_EL           ((semaphore & (1 << EL_DB)) > 0)
#define DB_ER           ((semaphore & (1 << ER_DB)) > 0)
#define DB_EE           ((semaphore & (1 << EE_DB)) > 0)

//
#define pulsedur        50                  //puse duration in us
#define delayafterdir   50                  //delay after set direction pin and before first pulse to come

//
volatile int32_t abspos          = 9999;             // absolute position after homing below

//
volatile uint8_t cmdindex        = 0;                //
uint8_t cmd[16];                            //

//
uint8_t buffx[129];                         //TX buffer
uint8_t buffx2[129];                        //TX buffer for morse

//
int tmpret;                                 //
uint32_t debugonly      = 0;                //
uint8_t incdcprintf     = 0;                //

//
const unsigned char* morseCode[] = {
    ".-",               // A
    "-...",             // B
    "-.-.",             // C
    "-..",              // D
    ".",                // E
    "..-.",             // F
    "--.",              // G
    "....",             // H
    "..",               // I
    ".---",             // J
    "-.-",              // K
    ".-..",             // L
    "--",               // M
    "-.",               // N
    "---",              // O
    ".--.",             // P
    "--.-",             // Q
    ".-.",              // R
    "...",              // S
    "-",                // T
    "..-",              // U
    "...-",             // V
    ".--",              // W
    "-..-",             // X
    "-.--",             // Y
    "--..",             // Z
    0x00
};   //morse code from A to Z

//
CDCReceiveCharTypes rcs = RX_NOTCPLT;       //
echoTypes rcs2 = RX_ECHO_OFF;               //
inputTypes it = RX_NONE;                    //

//
uint16_t Status;                            // used in hal_unlock
uint16_t delay;                             //fixme. global for speed adjust during jog

//
uint32_t semaphore = 0;

/* USER CODE END PV */

void SystemClock_Config(void);
static void MX_GPIO_Init(void);
static void MX_TIM2_Init(void);
static void MX_TIM3_Init(void);
static void MX_TIM1_Init(void);
/* USER CODE BEGIN PFP */

//DECLARES
void Tim1Start();
void Tim1Stop();
void TIM1Callback();
void Tim3Start();
void Tim3Stop();
void delay_us(uint32_t us);
void delay_ms(uint32_t ms);
void dot();
void dash();
uint8_t morse(const char *format, ... );

//
void readVariables();

//
void TIM3Callback();
uint32_t JogRampUp(uint8_t dir, uint32_t steps_in, uint8_t jsmod);
uint32_t constvel(uint8_t dir, uint32_t steps_in, uint8_t jsmode);
void volatile_memset(volatile void *s, int c, size_t n);

// //
void volatile_memset(volatile void *s, int c, size_t n) {
    volatile unsigned char *p = (volatile unsigned char *)s;
    while (n-- > 0) {
        *p++ = (unsigned char)c;
    }
}

uint8_t morse(const char *format, ... )
{
    // BKPT;
    va_list ap;

    uint8_t result;
    uint8_t len;

    unsigned char lettInMorse[8];

    uint8_t pseudoASCII;

    volatile_memset(buffx2, 0, sizeof(buffx2));

    va_start(ap, format);
    result = vsprintf(buffx2, format, ap);
    va_end(ap);

    len = strlen((const char*)buffx2);

    // here

    uint8_t cnt2 = 0;

    while (buffx[cnt2] > 0)
    {
        //
        if ( buffx2[cnt2] == 0x00 ) {
            break;
        }
        //
        if ( ( buffx2[cnt2] > 90 ) | ( buffx2[cnt2] < 65 ) ) {
            BKPT;
            break;
        }

        pseudoASCII = buffx2[cnt2]-65;

        uint8_t cnt = 0;

        while (1) {
            if (pseudoASCII > 25) {
                cdcprintf("%02x:%02x\r\n", pseudoASCII, buffx2[cnt2]);
                BKPT;
            }
            lettInMorse[cnt] = morseCode[pseudoASCII][cnt];
            if (lettInMorse[cnt] == 0) {
                //BKPT;
                break;
            }
            if (lettInMorse[cnt] == '.') {
                dot();
            }
            if (lettInMorse[cnt] == '-') {
                dash();
            }
            cnt++;
        }
        delay_ms(160);
        cnt2++;
    }
    return result; //
}

void dot()
{
    HAL_GPIO_WritePin(BUZZ_GPIO_Port, BUZZ_Pin, GPIO_PIN_RESET);
    delay_ms(80);
    HAL_GPIO_WritePin(BUZZ_GPIO_Port, BUZZ_Pin, GPIO_PIN_SET);
    delay_ms(80);
}

void dash()
{
    HAL_GPIO_WritePin(BUZZ_GPIO_Port, BUZZ_Pin, GPIO_PIN_RESET);
    delay_ms(200);
    HAL_GPIO_WritePin(BUZZ_GPIO_Port, BUZZ_Pin, GPIO_PIN_SET);
    delay_ms(80);
}

//
uint8_t cdcprintf(const char *format, ... )
{
    uint8_t result = USBD_FAIL;

    if (incdcprintf == 1) {
        // BKPT;
        return result;
    }

    incdcprintf = 1;

    va_list ap;

    volatile_memset(buffx, 0, sizeof(buffx));

    int vsprintfResult;

    va_start(ap, format);
        vsprintfResult = vsprintf(buffx, format, ap);
        if ( vsprintfResult < 0 ) {
            BKPT;
        }
    va_end(ap);
    uint8_t len = strlen((const char*)buffx);

    while (result != USBD_OK) {
        result = CDC_Transmit_FS(buffx, (uint16_t)len);
    }

    incdcprintf = 0;
    return result; //
}

/* USER CODE END PFP */

/* USER CODE BEGIN 0 */


//reciprocal
uint32_t reci(uint16_t x) {
    if (x == 0) return 0xFFFFFFFF; // div by 0
    return 1000000 / x;
}


//
void delay_ms(uint32_t ms)
{
    while(ms-- > 0) {
        delay_us(800);
    }
}

// 1MHz = 1us resolution. 3us lag here
void delay_us(uint32_t us)
{
    //
    if ( us < 4 ) {
        us = 4;
    }
    //
    if ( us > 65534 ) {
        us = 65534;
    }
    //
    TIM2->CNT = 0;
    TIM2->ARR = 65535;
    __HAL_TIM_CLEAR_FLAG(&htim2, TIM_FLAG_UPDATE);

    HAL_StatusTypeDef stat;
    stat = HAL_TIM_Base_Start(&htim2);
    if (stat != 0) {
        cdcprintf("TE SEGA SI EBA MAMATA:%x\t%x\t%x\r\n", stat, TIM2->CNT, TIM2->ARR);
        BKPT;
    }
    while (TIM2->CNT < us);
    HAL_TIM_Base_Stop(&htim2);
}

// homing
void home()
{
    morse("V");
     uint32_t tmp_ee_data_spsps = ee_data.spsps;
     uint32_t tmp_ee_data_spsmax = ee_data.spsmax;
     uint32_t tmp_ee_data_spsmin = ee_data.spsmin;

     ee_data.spsps=80;
     ee_data.spsmax=200;
     ee_data.spsmin=80;

     while ( PIN_JOGL_RESET | PIN_JOGL_RESET ) {
        cdcprintf("RELEASE JOGL AND JOGR BUTTONS\r\n");
     }

     cdcprintf("THANK YOU!\r\n");
     morse("G");

     delay_us(65530);

     while (1) {
         if (SEM_EL) {
            JogRampUp(1,1, 2);
            delay_us(65530);
            if (!SEM_EL) {
                abspos=0;
                cdcprintf("HOMING COMPLETE\r\n");
                break;
            }
         }
         if (SEM_ER) {
            JogRampUp(0,65535, 2);
            constvel(0,100000, 2);
         }
         if ( PIN_JOGL_RESET | PIN_JOGR_RESET | PIN_STEPL_RESET | PIN_STEPR_RESET) {
             break;
         }
     }
     ee_data.spsps=tmp_ee_data_spsps;
     ee_data.spsmax=tmp_ee_data_spsmax;
     ee_data.spsmin=tmp_ee_data_spsmin;

     semaphore &= ~(1 << IN_HOMING);
     morse("Z");
}

// ramp up. jsmode 0 - jog, 1 - step
uint32_t JogRampUp(uint8_t dir, uint32_t steps_in, uint8_t jsmode)
{
     uint32_t stepscompleted = 0;

     // 0 = L, 1 = R GPIO_PIN_SET for L
    if (dir == 0) {
        HAL_GPIO_WritePin(DIR_GPIO_Port, DIR_Pin, GPIO_PIN_SET);
         if (SEM_EL) {
            return 0;
         }
    }
    if (dir == 1) {
        HAL_GPIO_WritePin(DIR_GPIO_Port, DIR_Pin, GPIO_PIN_RESET);
         if (SEM_ER) {
            return 0;
         }
    }
    cdcprintf("JRU0:%d\r\n", dir);

    delay_us(delayafterdir);

    uint32_t tmpsps = ee_data.spsmin * 100;
    int dsps = ee_data.spsmax-ee_data.spsmin;            //

    cdcprintf("JRU1:%d\r\n", dsps);

    // HAL_GPIO_WritePin(PULSE_GPIO_Port, PULSE_Pin, GPIO_PIN_SET);       //checkme. prevantive

    while( ( tmpsps < ee_data.spsmax*100 )
            & (steps_in > 0 ) )
    {
        if ( SEM_EL & (dir == 0) ) {
            break;
        }
        if ( SEM_ER & (dir == 1) ) {
            break;
        }
        if ( PIN_JOGL_SET & (dir == 0) & (jsmode == 0) ) {
            break;
        }
        if ( PIN_JOGR_SET & (dir == 1) & (jsmode == 0) ) {
            break;
        }

        int delay_in_us = reci(tmpsps/100);
        // if ( (debugonly++ % 30) == 0) {
        //     cdcprintf("WDO:%d:%uus\r\n", tmpsps/100, delay_in_us);
        // }

        HAL_GPIO_WritePin(PULSE_GPIO_Port, PULSE_Pin, GPIO_PIN_RESET);
        delay_us(pulsedur-3);       // 3us lag
        HAL_GPIO_WritePin(PULSE_GPIO_Port, PULSE_Pin, GPIO_PIN_SET);
        delay_us(delay_in_us-3);

        if ( (dir == 0) ) {
            abspos--;
        }
        if ( (dir == 1) ) {
            abspos++;
        }

        tmpsps+=ee_data.spsps;
        steps_in--;
        stepscompleted++;
    }

    cdcprintf("JRU2:%d:%d\r\n", steps_in, stepscompleted);      //remainng steps to complete - steps_in
    cdcprintf("JRU3:%08d\r\n", abspos);
    return stepscompleted;
}

// constant velocity routine. jsmode 0 - jog, 1 - step, 2 - homing
uint32_t constvel(uint8_t dir, uint32_t steps_in, uint8_t jsmode)
{
    uint32_t stepscompleted = 0;

    cdcprintf("CV0:%d\r\n", steps_in);

    uint32_t tmpsps = ee_data.spsmax * 100;

    cdcprintf("CV1:%d\r\n", tmpsps);

    while( steps_in > 0 )
    {
        //
        if ( SEM_EL ) {
            break;
        }
        //
        if ( SEM_ER ) {
            break;
        }
        //
        if ( PIN_JOGL_SET & (dir == 0) & (jsmode == 0) ) {
            break;
        }
        //
        if ( PIN_JOGR_SET & (dir == 1) & (jsmode == 0) ) {
            break;
        }

        int delay_in_us = reci(tmpsps/100);

        HAL_GPIO_WritePin(PULSE_GPIO_Port, PULSE_Pin, GPIO_PIN_RESET);
        delay_us(pulsedur-3);       // 3us lag

        HAL_GPIO_WritePin(PULSE_GPIO_Port, PULSE_Pin, GPIO_PIN_SET);
        delay_us(delay_in_us-3);

        if ( (dir == 0) ) {
            abspos--;
        }
        if ( (dir == 1) ) {
            abspos++;
        }

        steps_in--;
        stepscompleted++;
    }

    cdcprintf("CV2:%d:%d\r\n", steps_in, stepscompleted);
    cdcprintf("CV3:%08d\r\n", abspos);
    return stepscompleted;
}
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
int main(void)
{

  /* USER CODE BEGIN 1 */

    semaphore = 0;

  /* USER CODE END 1 */

  /* MCU Configuration--------------------------------------------------------*/

  /* Reset of all peripherals, Initializes the Flash interface and the Systick. */
  HAL_Init();

  /* Configure the system clock */
  SystemClock_Config();

  /* Initialize all configured peripherals */
  MX_GPIO_Init();
  MX_TIM2_Init();
  MX_USB_DEVICE_Init();
  MX_TIM3_Init();
  MX_TIM1_Init();
  /* USER CODE BEGIN 2 */

  // HAL_TIM_Base_Start(&htim2);
  HAL_Delay(1200);      //wait for USB reenumeration

  //boot pritnf
  volatile_memset(cmd, 0, sizeof(cmd));

  //
  cdcprintf("Malinovski 12.2025 (c) smooker&chichko %d \r\n");

  //
  HAL_TIM_RegisterCallback(&htim3, HAL_TIM_PERIOD_ELAPSED_CB_ID, TIM3Callback);
  HAL_TIM_RegisterCallback(&htim1, HAL_TIM_PERIOD_ELAPSED_CB_ID, TIM1Callback);

  //
  Status = HAL_FLASH_Unlock();      //fixme. move the same into ee_init and into ww_writevariable
  assert_param(Status == HAL_OK);
  if(Status != HAL_OK) {
    cdcprintf("HAL_FLASH_Unlock() returned %d\r\n", Status);
  };

  cdcprintf("EE_Init returned %d\r\n", EE_Init());

  // cdcprintf("HAL_GetUIDw0()=%lu\r\n", HAL_GetUIDw0());
  // cdcprintf("HAL_GetUIDw1()=%lu\r\n", HAL_GetUIDw1());
  // cdcprintf("HAL_GetUIDw2()=%lu\r\n", HAL_GetUIDw2());

  cdcprintf("HAL_GetDEVID=%lu\r\n", HAL_GetDEVID());
  //For medium-density devices, the device ID is 0x410

  cdcprintf("Flash size=%ukiB\r\n", *(const uint16_t*)FLASHSIZE_BASE);

  dumpVars();
  // dumpIO();


  // states of the outputs
  HAL_GPIO_WritePin(PULSE_GPIO_Port, PULSE_Pin, GPIO_PIN_SET);
  HAL_GPIO_WritePin(DIR_GPIO_Port, DIR_Pin, GPIO_PIN_SET);

  morse("VGZ");
  unsigned char* str = "-3.014159";
  tuple64 t = str2float((uint8_t*)str);
  BKPT;

  /* USER CODE END 2 */

  /* Infinite loop */
  /* USER CODE BEGIN WHILE */
  while (1)
  {
    //MOVEMENT COMMANDS

    if ( SEM_JOGL ) {
            // cdcprintf("JOGL\r\n");
            JogRampUp(0, 1000000, 0);
            constvel(0, 1000000, 0);
            semaphore &= ~( 1 << JOGL);
            // cdcprintf("JOGL END\r\n");
    }

    //JOGR - buttons to GND, limit switches too
    if ( SEM_JOGR ) {
        // cdcprintf("JOGR\r\n");
        JogRampUp(1, 1000000, 0);
        constvel(1, 1000000, 0);
        semaphore &= ~( 1 << JOGR);
        // cdcprintf("JOGR END\r\n");
    }

    if ( SEM_JOGSTEPL ) {
        // cdcprintf("JSL0\r\n");
        JogRampUp(0, ee_data.jogsteps, 0);
        semaphore &= ~( 1 << JOGSTEPL);
        // cdcprintf("JSL1\r\n");
    }

    if ( SEM_JOGSTEPR ) {
        // cdcprintf("JSR0\r\n");
        JogRampUp(1, ee_data.jogsteps, 0);
        semaphore &= ~( 1 << JOGSTEPR);
        // cdcprintf("JSR1\r\n");
    }

    if ( SEM_STEPL ) {
        // cdcprintf("STL0\r\n");
        uint32_t remsteps = JogRampUp(0, ee_data.ssteps, 1);
        uint32_t remsteps4rd = remsteps;
        remsteps = ee_data.ssteps - remsteps;
        constvel(0, remsteps, 1);

        semaphore &= ~( 1 << STEPL);
        // cdcprintf("STL1\r\n");
    }
    if ( SEM_STEPR ) {
        // cdcprintf("STR0\r\n");
        uint32_t remsteps = JogRampUp(1, ee_data.ssteps, 1);
        uint32_t remsteps4rd = remsteps;
        remsteps = ee_data.ssteps - remsteps;
        constvel(1, remsteps, 1);
        semaphore &= ~( 1 << STEPR);
        // cdcprintf("STR1\r\n");
    }

    if ( SEM_IN_HOMING ) {
        // cdcprintf("HOMING\r\n");
        home();
        semaphore &= ~( 1 << IN_HOMING);
        // cdcprintf("HOMING END\r\n");
    }


     //END OF MOVEMENTS

    if (rcs == RX_CR) {
        // we were in variable entry mode
        if (rcs2 == RX_ECHO_ON) {
            rcs2 = RX_ECHO_OFF;
            // parse variable values
            if (it == RX_VAR1) {
                tmpret = sscanf(cmd, "%" SCNd32, &ee_data.spsmax);
                cdcprintf(" spsmax value : %d\r\n", ee_data.spsmax);
                cdcprintf("ret  : %d\r\n", tmpret);
                eewrite32(1, ee_data.spsmax);
                eeread32(1, &ee_data.spsmax);
                cdcprintf(" spsmax value : %d\r\n", ee_data.spsmax);
            }
            if (it == RX_VAR1A) {
                int tmpret = sscanf(cmd, "%f", &ee_data.spsmax2);
                //checkme what sscanf returns
                cdcprintf("\r\n you typed: %s\r\n returned : %d\r\n spsmax nat: %f\r\n", cmd, tmpret, ee_data.spsmax2);
                cdcprintf("we get %08x\r\n", ee_data.spsmax2);
            }

            else if (it == RX_VAR2) {
                tmpret = sscanf(cmd, "%" SCNd32, &ee_data.spsmin);
                cdcprintf(" spsmin value : %d\r\n", ee_data.spsmin);
                cdcprintf("ret  : %d\r\n", tmpret);
                eewrite32(2, ee_data.spsmin);
                eeread32(2, &ee_data.spsmin);
                cdcprintf(" spsmin value : %d\r\n", ee_data.spsmin);
            }
            else if (it == RX_VAR3) {
                tmpret = sscanf(cmd, "%" SCNd32, &ee_data.spsps);
                cdcprintf(" spsps value : %d\r\n", ee_data.spsps);
                cdcprintf("ret  : %d\r\n", tmpret);
                eewrite32(3, ee_data.spsps);
                eeread32(3, &ee_data.spsps);
                cdcprintf(" spsps value : %d\r\n", ee_data.spsps);
            }
            else if (it == RX_VAR4) {
                tmpret = sscanf(cmd, "%" SCNd32, &ee_data.jogsteps);
                cdcprintf(" jogsteps value : %d\r\n", ee_data.jogsteps);
                cdcprintf("ret  : %d\r\n", tmpret);
                eewrite32(4, ee_data.jogsteps);
                eeread32(4, &ee_data.jogsteps);
                cdcprintf(" jogsteps value : %d\r\n", ee_data.jogsteps);
            }
            else if (it == RX_VAR5) {
                tmpret = sscanf(cmd, "%" SCNd32, &ee_data.ssteps);
                cdcprintf(" ssteps value : %d\r\n", ee_data.ssteps);
                cdcprintf("ret  : %d\r\n", tmpret);
                eewrite32(5, ee_data.ssteps);
                eeread32(5, &ee_data.ssteps);
                cdcprintf(" ssteps value : %d\r\n", ee_data.ssteps);
            }
            else {
                cdcprintf(" WHAT THE FUCK ?!\r\n", cmd);
            }
        }
        // parse commands
        else if (strcmp(cmd, "reset") == 0) {
            cdcprintf("RES:reset\r\n");
            NVIC_SystemReset();
        }
        // else if (strcmp(cmd, "home") == 0) {
        //     cdcprintf("RES:dump %s\r\n", cmd);
        //     home();
        // }
        else if (strcmp(cmd, "dump") == 0) {
            cdcprintf("RES:dump %s\r\n", cmd);
            dumpVars();
        }
        // else if (strcmp(cmd, "dumpio") == 0) {
        //     cdcprintf("RES:dumpio %s\r\n", cmd);
        //     dumpIO();
        // }
        // else if (strcmp(cmd, "help") == 0) {
        //     help();
        // }
        else if (strcmp(cmd,"a") == 0) {
            cdcprintf("enter value for spsmax:");
            rcs2 = RX_ECHO_ON;
            it = RX_VAR1;
        }
        else if (strcmp(cmd,"a1") == 0) {
            cdcprintf("enter value for spsmax in mm/s:");
            rcs2 = RX_ECHO_ON;
            it = RX_VAR1A;
        }
        else if (strcmp(cmd,"b") == 0) {
            cdcprintf("enter value for spsmin:");
            rcs2 = RX_ECHO_ON;
            it = RX_VAR2;
        }
        else if (strcmp(cmd,"c") == 0) {
            cdcprintf("enter value spsps:");
            rcs2 = RX_ECHO_ON;
            it = RX_VAR3;
        }
        else if (strcmp(cmd,"d") == 0) {
            cdcprintf("enter value jogsteps:");
            rcs2 = RX_ECHO_ON;
            it = RX_VAR4;
        }
        else if (strcmp(cmd,"e") == 0) {
            cdcprintf("enter value ssteps:");
            rcs2 = RX_ECHO_ON;
            it = RX_VAR5;
        }
        else {
            cdcprintf("RES: UNKNOWN COMMAND: %s\r\n", cmd);
        }
        volatile_memset(cmd, 0, sizeof(cmd));
        rcs = RX_NOTCPLT;      //reset status
    } else if (rcs == RX_OF) {
        cdcprintf("\r\nRES: OVERFLOW.\r\n");    //keep it smaller
        rcs2 = RX_ECHO_OFF;
        it = RX_NONE;
        volatile_memset(cmd, 0, sizeof(cmd));
    }

    /* USER CODE END WHILE */

    /* USER CODE BEGIN 3 */
  }
  /* USER CODE END 3 */
}
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

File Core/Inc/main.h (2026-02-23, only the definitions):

#define BKPT asm("bkpt 255")
#define LED_USER_Pin GPIO_PIN_13
#define LED_USER_GPIO_Port GPIOC
#define BUTT_JOGL_Pin GPIO_PIN_6
#define BUTT_JOGL_GPIO_Port GPIOA
#define BUTT_JOGL_EXTI_IRQn EXTI9_5_IRQn
#define BUTT_JOGR_Pin GPIO_PIN_7
#define BUTT_JOGR_GPIO_Port GPIOA
#define BUTT_JOGR_EXTI_IRQn EXTI9_5_IRQn
#define BUTT_STEPL_Pin GPIO_PIN_0
#define BUTT_STEPL_GPIO_Port GPIOB
#define BUTT_STEPL_EXTI_IRQn EXTI0_IRQn
#define BUTT_STEPR_Pin GPIO_PIN_1
#define BUTT_STEPR_GPIO_Port GPIOB
#define BUTT_STEPR_EXTI_IRQn EXTI1_IRQn
#define ES_L_Pin GPIO_PIN_10
#define ES_L_GPIO_Port GPIOB
#define ES_L_EXTI_IRQn EXTI15_10_IRQn
#define ES_R_Pin GPIO_PIN_11
#define ES_R_GPIO_Port GPIOB
#define ES_R_EXTI_IRQn EXTI15_10_IRQn
#define HX711_DATA_Pin GPIO_PIN_13
#define HX711_DATA_GPIO_Port GPIOB
#define HX711_CLK_Pin GPIO_PIN_14
#define HX711_CLK_GPIO_Port GPIOB
#define BUZZ_Pin GPIO_PIN_15
#define BUZZ_GPIO_Port GPIOB
#define PULSE_Pin GPIO_PIN_8
#define PULSE_GPIO_Port GPIOA
#define DIR_Pin GPIO_PIN_9
#define DIR_GPIO_Port GPIOA

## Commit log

2025-12-09 reverted to working state with stm32cubemx generated cdc
    [main.c, scales_stepper_malinovski.ioc]
2025-12-28 udev rules working. the problem was ATTRS{interface}="intrerface name". Have to find a way to get teh name
    [main.c, main.h]
2026-01-12 migrated to STM32F103C8T6
2026-01-16 keyboard input and limit switches tested
2026-01-20 direction in go. Vmax during stage2 fixed.
    [main.c]
2026-01-24 hybrid buttons... e.g. event and level based...
2026-01-24 steps has to be event based too. no missed event till now :)
    [main.c]
2026-01-28 BUG. gostep in interrupt routine instead in main
    [main.c, scales_stepper_stm32.ioc]
2026-02-07 rising and falling on pb10 was wrong
    [main.c, scales_stepper_stm32.ioc]
2026-02-10 USB commands OK. not_cmplete flag was on the wrong place
    [main.c]
2026-02-14 fixed break from while in rampup and constvel on button release
    [main.c, scales_stepper_stm32.ioc]
2026-02-15 usb disconnection solved hUsbDeviceFS.dev_state != USBD_STATE_CONFIGURED
    [main.c]
2026-02-15 pcb work
    [scales_stepper_stm32.kicad_pcb, scales_stepper_stm32.kicad_sch]
2026-02-16 morse code
    [scales_stepper_stm32.kicad_pcb, scales_stepper_stm32.kicad_sch]
2026-02-16 morse fixed with right timing
    [main.c]
2026-02-16 morse ok
    [scales_stepper_stm32.kicad_pcb]
2026-02-23 float only for printf/vsprintf. sscanf had already
2026-02-24 general refactoring. getting rid of nanolibc printf and sscanf

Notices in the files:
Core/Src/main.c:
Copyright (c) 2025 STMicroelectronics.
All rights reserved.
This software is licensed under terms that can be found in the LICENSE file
